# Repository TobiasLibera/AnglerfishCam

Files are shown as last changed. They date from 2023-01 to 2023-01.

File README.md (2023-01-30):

# AnglerfishCam

An easy to print cam mount for the Creality Ender 3.<br></br>

Thingiverse of this project:\
[Printing Data](https://www.thingiverse.com/thing:5822809)<br></br>

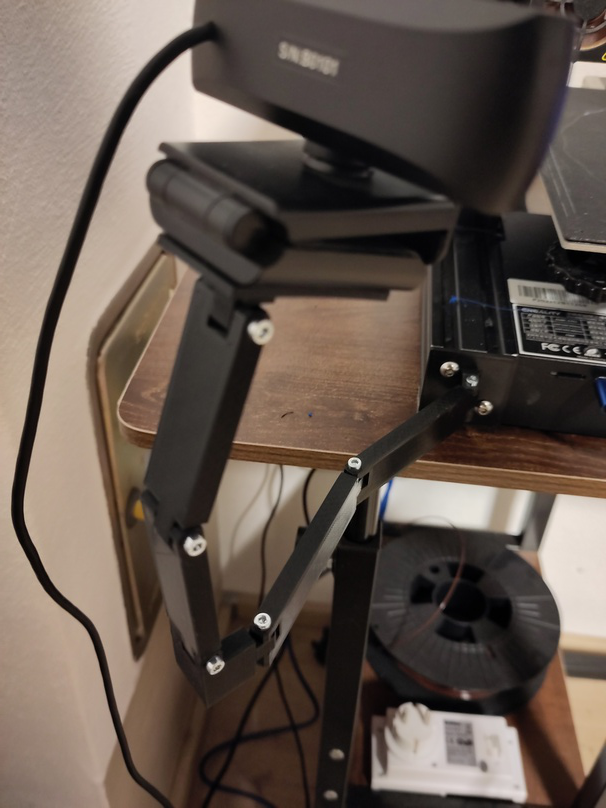
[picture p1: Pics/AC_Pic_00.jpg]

<br></br>

## Description ##

The whole mount is designed in a modular way. There are parts in different lengths, so you can place your camera where ever you want. The pieces are joined together with a press fit. For this you will need a M3 screw with _at least_ 18mm length, as well as a M3 hex nut for every join you realize. The whole thing is to be joined to the Ender 3 by the two screws at the lower left, which hold the electronics case.\
The pieces are designed very simple and should be printed ***easy and fast***.\
The AnglerfishCam mount is designed for cams, which have a thread at the bottom side. Therefor I have designed some plates, with different hole sizes. In particular holes for 3mm, 4mm or 5mm bolts.\
I invite you to design this part as you need it for your cam by yourself, or to let me know what could be done better to improve compatibility with different cams.<br></br>

## Printing ##

A list of my printing settings as well as the corresponding printing times can be found in the documentation folder. Note that this are just ***my*** settings. I am pretty sure, a lot of you will find better settings.\
I recommend to at first print the ```AC_Beam_20.STL``` two times, to ensure the fit is working well.\
If it doesn't work out, you can use the STEP files to easily adjust the fits to your needs.\

For the sunk of the hex nut, there is ***maybe support needed***. If you are convinced, you will get it printed properly without supports, do so.<br></br>

## Joining ##

The parts are designed for being used with a M3 hex nut (ISO 4032 or ISO 4033). For the other end I used a M3 socket-head screw (ISO 4762) as I am convinced, once adjusted, you will not change the orientation of the cam very often. But as long the screw you use is M3 and has a thread length of at least 18mm (or more) it should work out fine. To use some kind of thumbscrew could also be useful, I guess.\
Also, please mind that the screw will stick over the edge of the beam parts if the thread is longer then 20mm.<br></br>

## Donations ##

I want to dedicate this work to organizations which commit themselfs to helping people with mental illness.
Therefor I want to ask you to donate a little tip for one of the following organizations on www.betterplace.org, as long as you feel comfortable with that.\
I do not gain anything from it, and the organizations don't even know, I am sharing their links.
<br></br>
[Irrsinnig Menschlich e.V.](https://www.betterplace.org/de/organisations/2508-irrsinnig-menschlich-e-v)\
Translated Name: *Insanely Humane* (registered association)
<br></br>
[Stiftung Deutsche Depressionshilfe](https://www.betterplace.org/de/organisations/24384-stiftung-deutsche-depressionshilfe)\
Translated Name: *German Depression Help* (foundation)
<br></br>
***Thank you very much!***

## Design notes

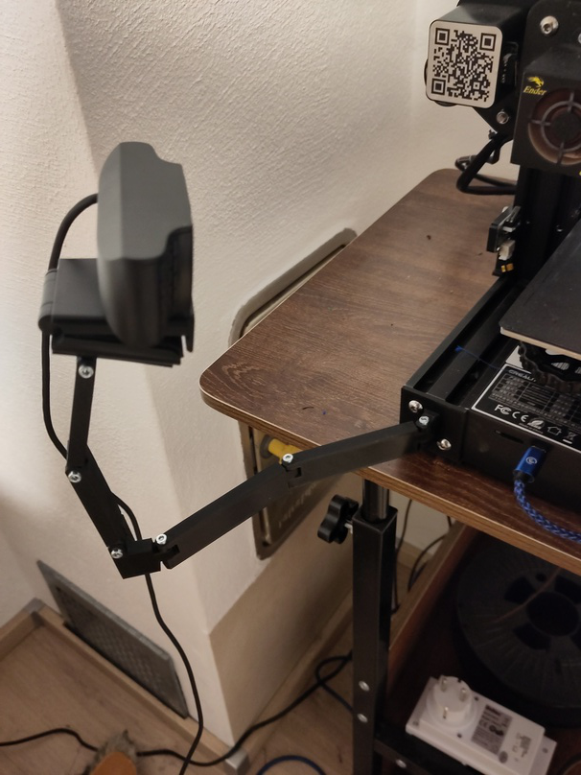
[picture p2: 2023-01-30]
Pics/AC_Pic_01.jpg

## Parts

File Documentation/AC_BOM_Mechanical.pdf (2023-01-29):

BOM – Mechanical Parts | 2023-01-29 Tobias Libera
Name | Description | Standard | Amount | Link / Comment
M3x20 Screw | Socket-Head Screw | ISO 4762 | x | One for every joining
M3 Nut | Hex Nut | ISO 4032 | x | One for every joining

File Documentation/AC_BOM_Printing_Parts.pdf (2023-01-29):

BOM – Printing Parts | 2023-01-29 Tobias Libera
File Name | Amount | Material | Infill Density | Speed | Layer Thickness | Support | Adhesion | Material Weight | Time
AC_Beam_20 | Select as much as you need | PLA | 40 % | 50 mm/s | 0.2 mm | yes | no | 2g | 23m
AC_Beam_40 | | PLA | 40 % | 50 mm/s | 0.2 mm | yes | no | 5g | 36m
AC_Beam_60 | | PLA | 40 % | 50 mm/s | 0.2 mm | yes | no | 7g | 49m
AC_Beam_80 | | PLA | 40 % | 50 mm/s | 0.2 mm | yes | no | 9g | 1h 2m
AC_Beam_100 | | PLA | 40 % | 50 mm/s | 0.2 mm | yes | no | 11g | 1h 15m
AC_Beam_120 | | PLA | 40 % | 50 mm/s | 0.2 mm | yes | no | 13g | 1h 29m
AC_CamConnect_Generic_3 | Choose 1 | PLA | 40 % | 50 mm/s | 0.2 mm | yes | no | 5g | 39m
AC_CamConnect_Generic_4 | | PLA | 40 % | 50 mm/s | 0.2 mm | yes | no | 4g | 39m
AC_CamConnect_Generic_5 | | PLA | 40 % | 50 mm/s | 0.2 mm | yes | no | 4g | 39m
AC_CamConnect_Nulaxy_C900 | | PLA | 40 % | 50 mm/s | 0.2 mm | yes | no | 4g | 39m
AC_PrinterConnect | 1 | PLA | 40 % | 50 mm/s | 0.2 mm | yes | no | 5g | 46m
AC_Transition | 1 | PLA | 40 % | 50 mm/s | 0.2 mm | yes | no | 5g | 47m

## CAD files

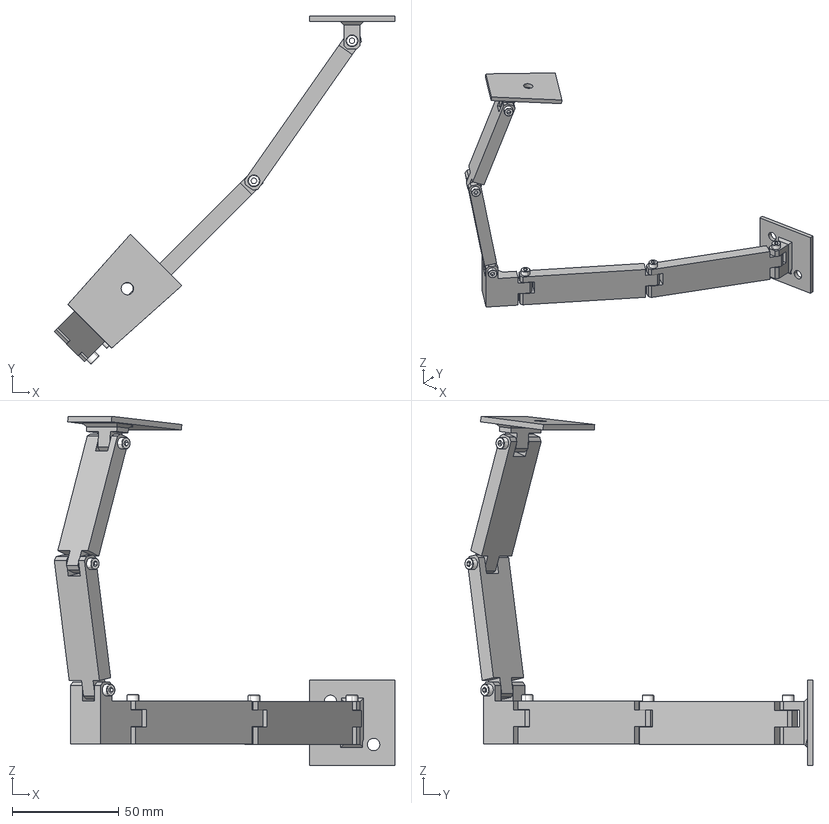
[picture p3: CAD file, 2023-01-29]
3D-Files/STEP/AC_Assembly_AnglerfishCam_Sample.STEP
159.3 x 162.8 x 163.5 mm
AC_PrinterConnect
AC_Beam_80 x 2
AC_Transition
AC_Beam_60 x 2
AC_CamConnect___Nulaxy_C900
AC_PurchaseMechanical_HexNut_ISO4032_M3 x 6
AC_PurchaseMechanical_SocketHeadScrew_ISO4762_M3x20 x 6

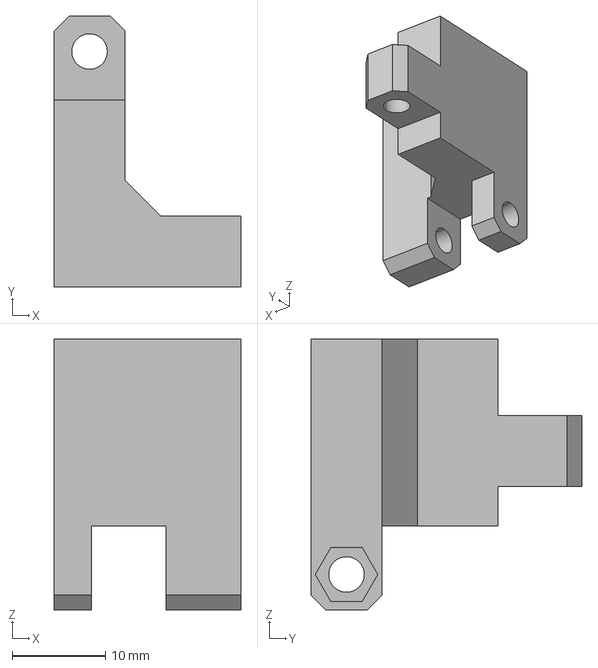
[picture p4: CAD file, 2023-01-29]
3D-Files/STEP/Printing_Parts/AC_Transition.STEP
20.0 x 29.0 x 29.0 mm

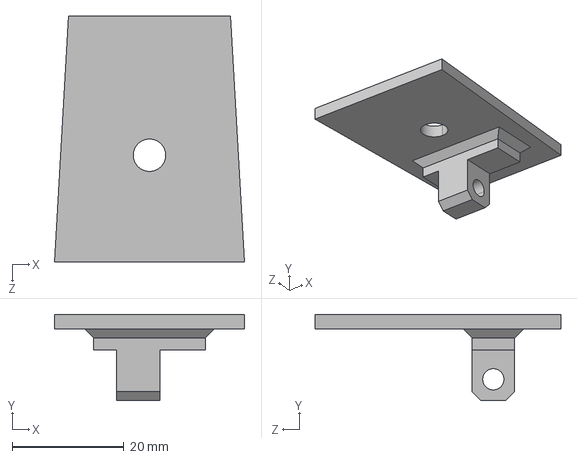
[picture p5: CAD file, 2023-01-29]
3D-Files/STEP/Printing_Parts/AC_CamConnect___Nulaxy_C900.STEP
34.0 x 15.4 x 44.0 mm

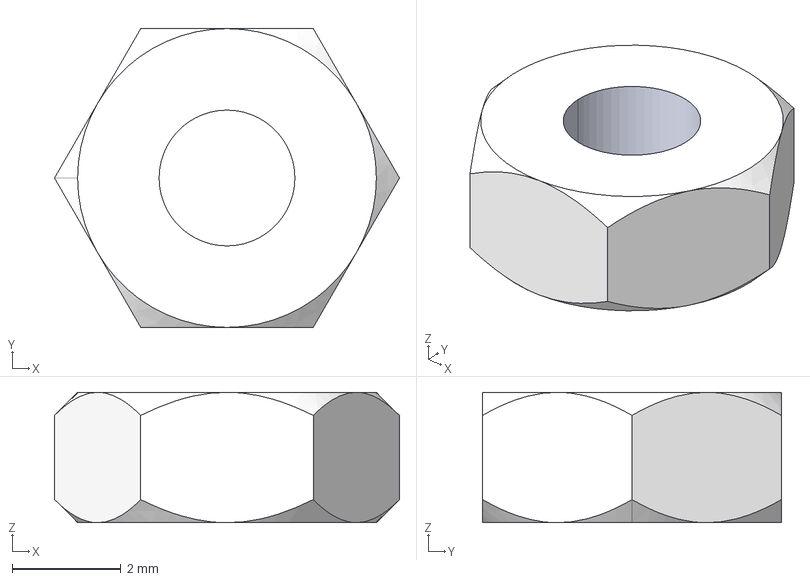
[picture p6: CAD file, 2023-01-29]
3D-Files/STEP/Purchase_Mechanical/AC_PurchaseMechanical_HexNut_ISO4032_M3.STEP
6.35 x 5.50 x 2.40 mm

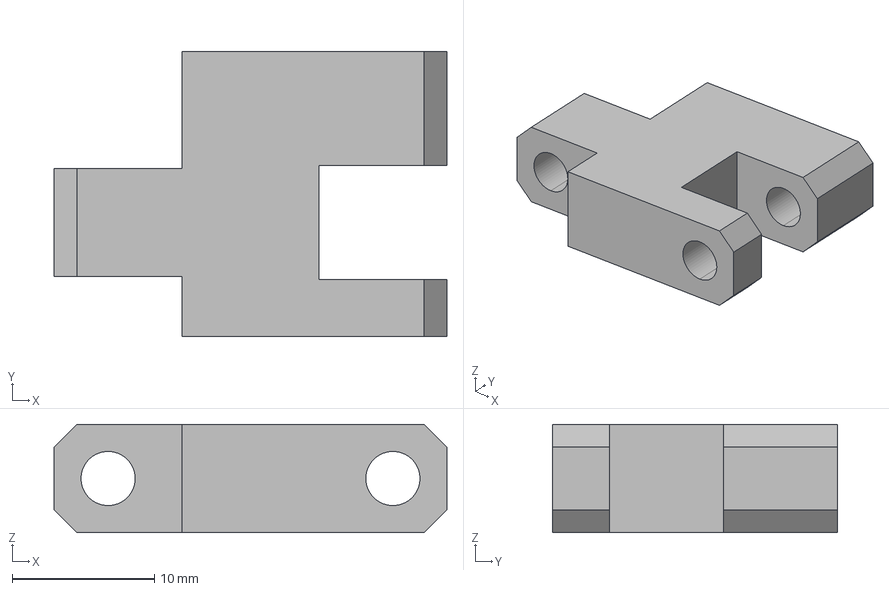
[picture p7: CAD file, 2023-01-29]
3D-Files/STEP/Printing_Parts/AC_Beam_20.STEP
27.6 x 20.0 x 7.60 mm

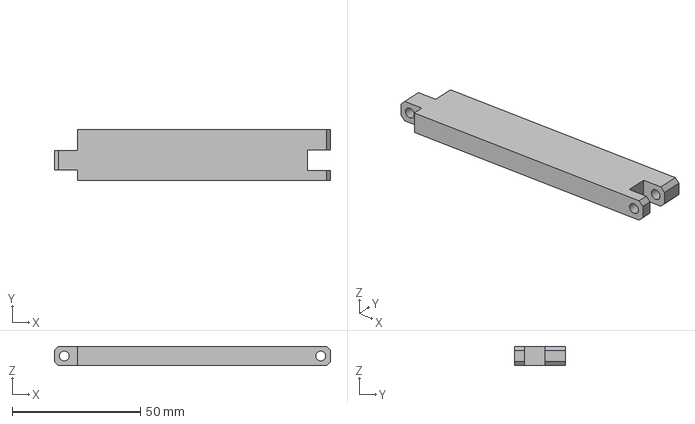
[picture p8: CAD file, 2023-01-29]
3D-Files/STEP/Printing_Parts/AC_Beam_100.STEP
107.6 x 20.0 x 7.60 mm

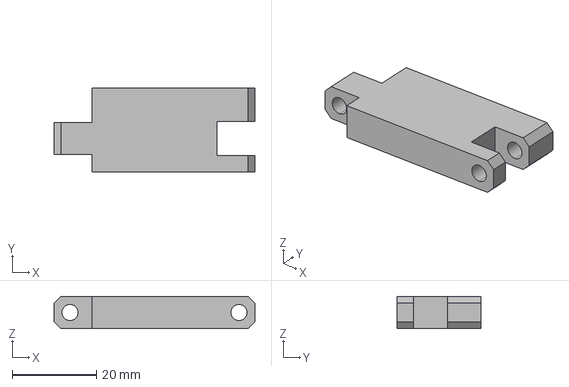
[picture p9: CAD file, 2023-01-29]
3D-Files/STEP/Printing_Parts/AC_Beam_40.STEP
47.6 x 20.0 x 7.60 mm

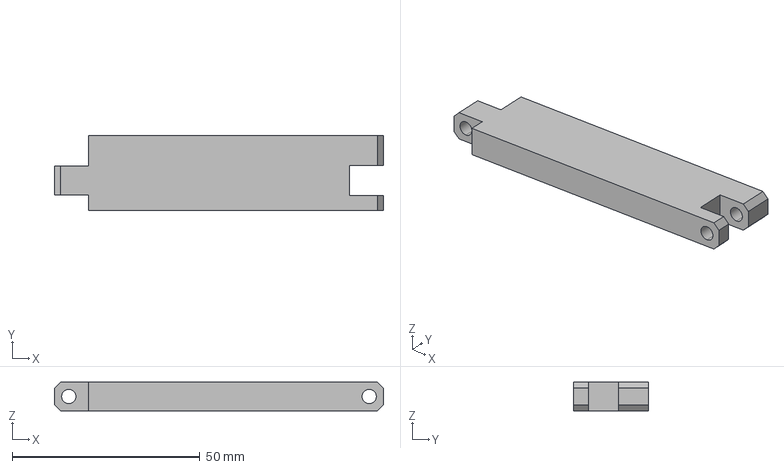
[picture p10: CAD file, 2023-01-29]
3D-Files/STEP/Printing_Parts/AC_Beam_80.STEP
87.6 x 20.0 x 7.60 mm

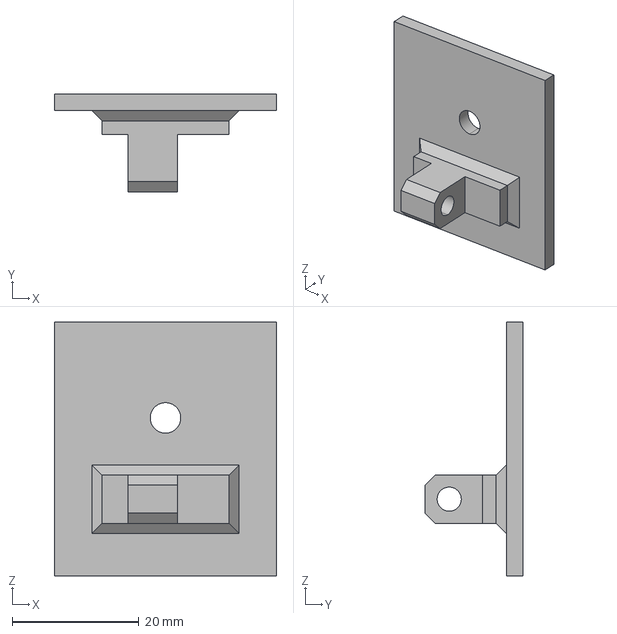
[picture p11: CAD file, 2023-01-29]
3D-Files/STEP/Printing_Parts/AC_CamConnect_Generic_4.STEP
35.0 x 15.4 x 40.0 mm

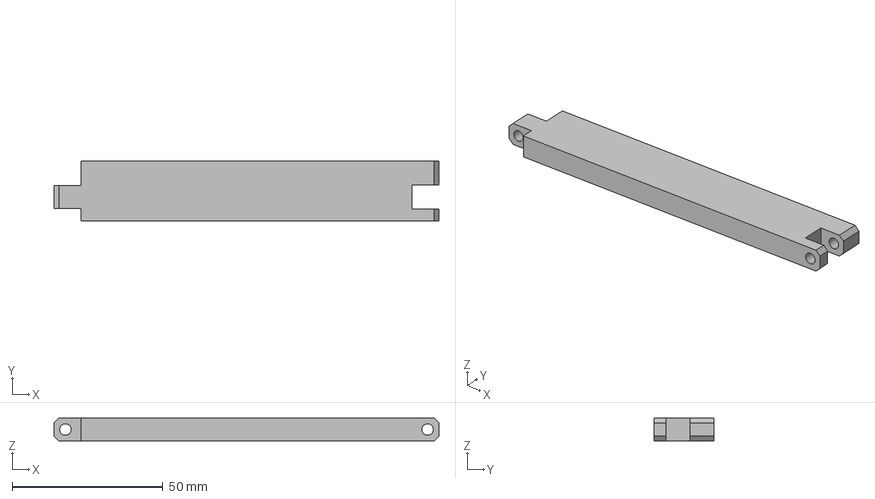
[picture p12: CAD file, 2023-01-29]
3D-Files/STEP/Printing_Parts/AC_Beam_120.STEP
127.6 x 20.0 x 7.60 mm

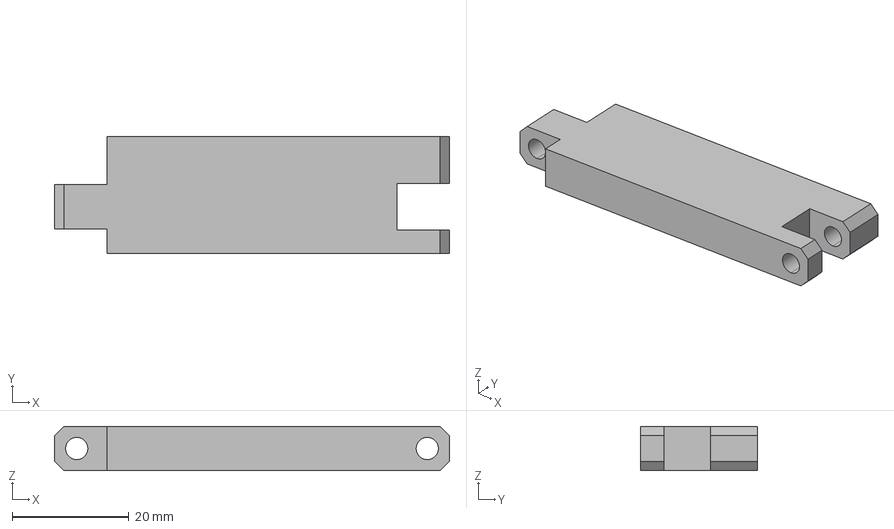
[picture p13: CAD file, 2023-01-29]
3D-Files/STEP/Printing_Parts/AC_Beam_60.STEP
67.6 x 20.0 x 7.60 mm

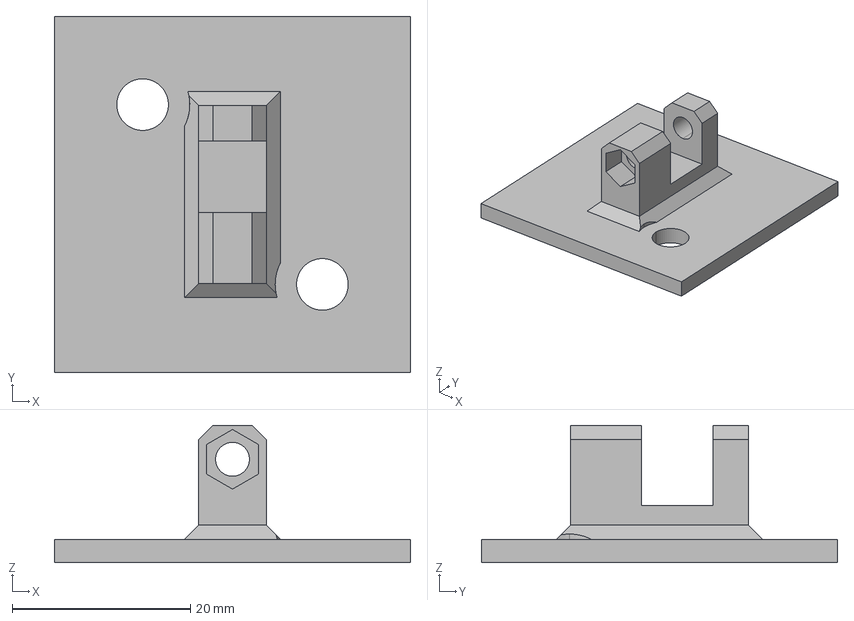
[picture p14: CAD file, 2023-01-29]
3D-Files/STEP/Printing_Parts/AC_PrinterConnect.STEP
40.0 x 40.0 x 15.4 mm

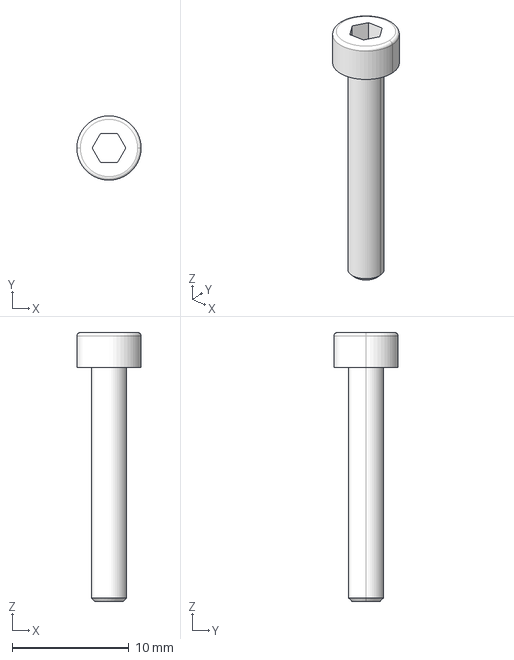
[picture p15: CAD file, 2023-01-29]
3D-Files/STEP/Purchase_Mechanical/AC_PurchaseMechanical_SocketHeadScrew_ISO4762_M3x20.STEP
5.50 x 5.50 x 23.0 mm

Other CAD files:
3D-Files/STEP/Printing_Parts/AC_CamConnect_Generic_5.STEP
3D-Files/STEP/Printing_Parts/AC_CamConnect_Generic_3.STEP
3D-Files/STL/AC_Beam_100.STL
3D-Files/STL/AC_Beam_120.STL
3D-Files/STL/AC_Beam_20.STL
3D-Files/STL/AC_Beam_40.STL
3D-Files/STL/AC_Beam_60.STL
3D-Files/STL/AC_Beam_80.STL
3D-Files/STL/AC_CamConnect_Generic_3.STL
3D-Files/STL/AC_CamConnect_Generic_4.STL
3D-Files/STL/AC_CamConnect_Generic_5.STL
3D-Files/STL/AC_CamConnect___Nulaxy_C900.STL
3D-Files/STL/AC_PrinterConnect.STL
3D-Files/STL/AC_Transition.STL
